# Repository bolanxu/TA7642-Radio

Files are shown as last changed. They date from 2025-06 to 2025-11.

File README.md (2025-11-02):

# TA7642 Radio

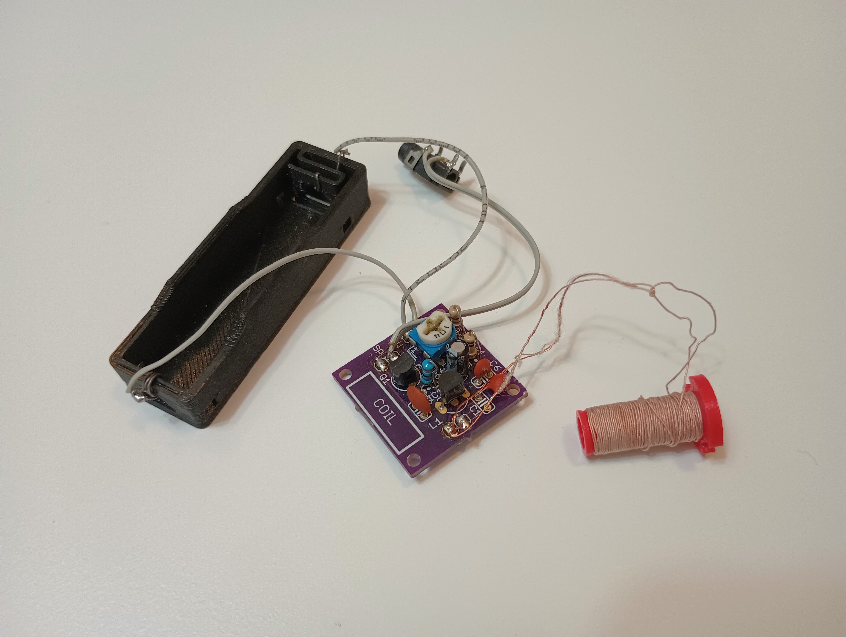
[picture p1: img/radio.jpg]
  
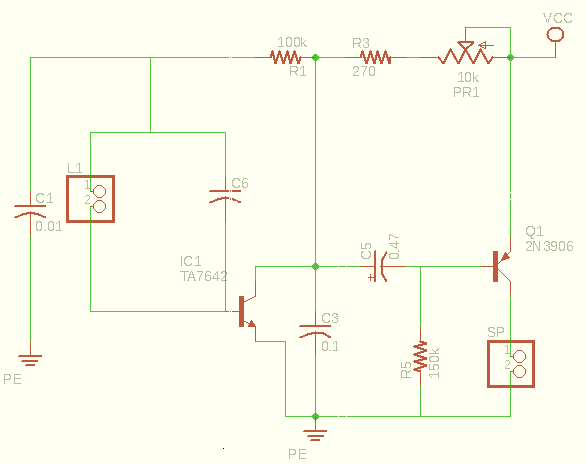
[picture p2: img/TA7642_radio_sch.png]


A very tiny pocket AM radio that runs from a single 1.5 V battery. It's a simple, low‑power receiver built around the TA7642 AM demodulator/amplifier IC with a small tuning coil and a coupling transistor to drive headphones. I designed this as a kit and created the PCB in 2021 (a 5th grade project) to learn about radios, basic electronics, and PCB design. More information in the `/docs` folder (The docs were written by me as a 5th grader, don't expect the best english 😅).

## Features
- Pocket‑sized AM radio
- Powered by a single 1.5 V cell (AA/AAA) or possibly a small 1.5V button battery
- TA7642 AM demodulator and amplifier IC
- Tuning via LC tank (coil + variable capacitor)
- Simple output amplifier transistor (Q1) for headphones/earbuds
- Designed as a kit with a compact PCB

## Circuit (overview)
- The LC tank (coil + capacitor) selects the desired AM frequency.  
- The TA7642 performs RF detection (demodulation) and provides a small amount of audio amplification.  
- A single transistor (Q1) follows the TA7642 to raise the audio level enough for headphones or small earbuds.  
- The schematic is shown above (`img/TA7642_radio_sch.png`)..

## Usage
1. Connect a fresh 1.5 V battery (observe polarity).
2. Plug headphones or earbuds into the audio jack or connect to the audio pads.
3. Slowly adjust the ferrite rod in the coil until you hear a station.
4. Fine‑tune the coil/trimmer for best reception and volume.

Note: This radio is optimized for strong local AM stations and will have limited sensitivity compared with larger receivers.

## Tuning and performance tips
- Use low‑impedance earbuds for better volume from the simple output stage.
- If reception is weak, try repositioning the coil or extending an earbud wire as an antenna.
- Small changes in the tuning capacitor or coil turns produce noticeable frequency shifts—tweak gently.
- The TA7642 and a single‑transistor buffer are designed for simplicity and low voltage operation; don't expect the same performance as higher‑powered receivers.

Enjoy building and listening, tiny radios are a great way to learn the fundamentals of RF and analog electronics!

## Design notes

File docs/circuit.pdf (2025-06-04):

### TA7642 Radio Project

This project, features the basics of a AM Radio. In this project, you will build an AM Radio from 4 capacitors, 4 resistors, a coil, a transistor, and an IC. Below explains the main parts of the radio:

Transistor:
The transistor, Q1, it has to be P-N-P and a small signal amplifier. If you do use a N-P-N type transistor you would need to change the
circuit.

Power source:
Since the operating voltage of the TA7642 IC is no more than 1.5 V, the power in this circuit should also be no more than 1.5 V. If you do use a voltage larger than 1.5 V than your circuit may have a risk of IC and some other components will burn out.

Pot. :
The pot in this circuit is needed for good sensitivity. This pot serves as a adjuster for gain on the TA7642. When the radio signal you are receiving is very strong, you need to adjust the pot to make the gain lower. This way, you can hear the strong station clearly. The same happens when there is a weak station.

TA7642 IC:
This IC (Integrated Circuit) is a IC for amplifying and demodulation purposes. This IC can only receive AM broadcast signals because of its way of demodulation.

C6 capacitor and L1:
This is a LC circuit, you use this to tune in to radio signals. This part of the circuit chooses out one signal from all the others. When you adjust the capacitor or the coil, you are tuning the oscillation frequency between the to components to match the frequency of the radio station.

Q1:
This transistor is used to amplify the audio output signal of the TA7642. Since the audio output signal of the TA7642 is too small to be heard by normal headphones, the transistor can amplify it and gain the volume of the output signal so that it can be heard.

Page 1 out of 3

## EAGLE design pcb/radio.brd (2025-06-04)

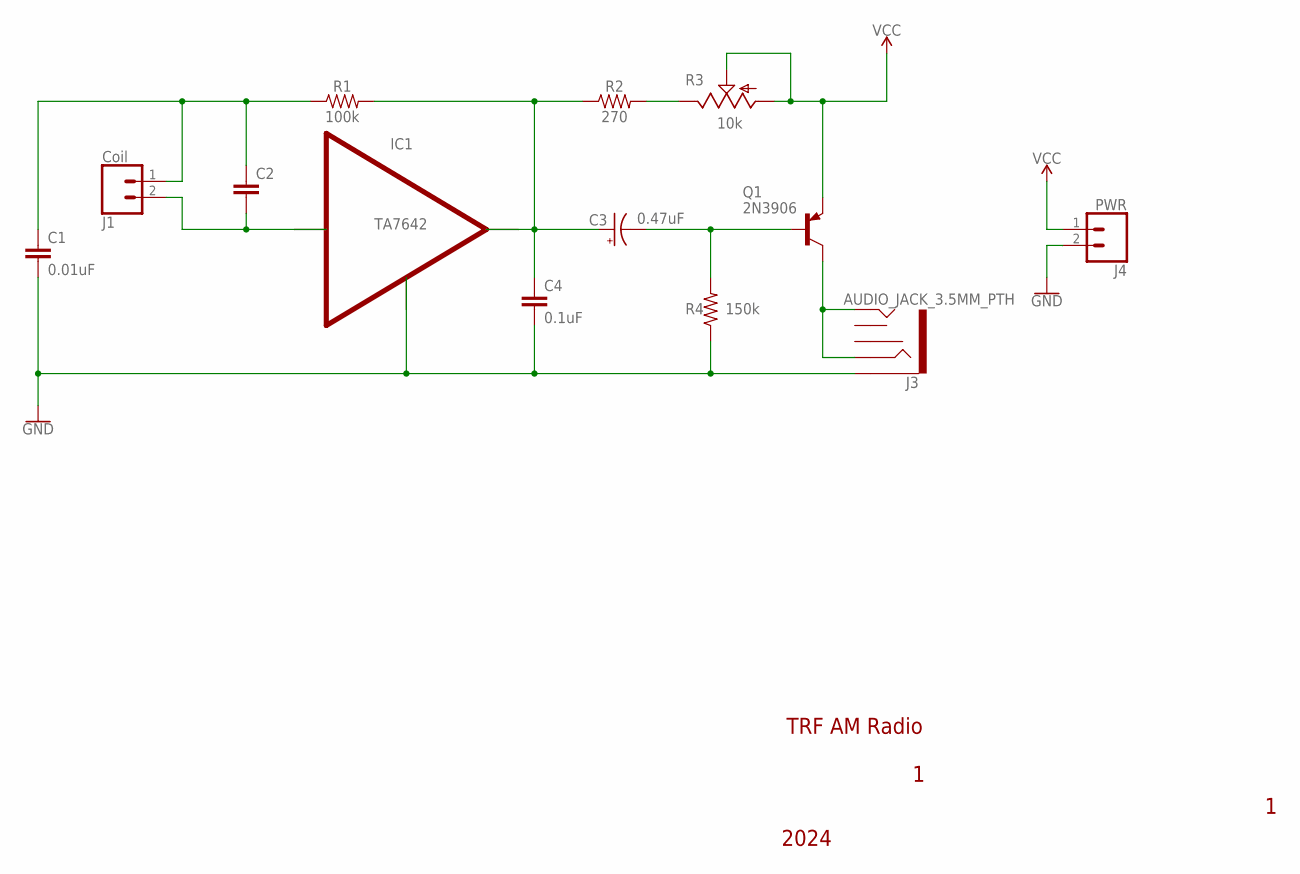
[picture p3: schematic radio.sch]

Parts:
C1: 0.01uF; CAP-PTH-2.54
C2: 22PF-PTH-2.54MM-200V-5%; CAP-PTH-2.54
C3: 0.47uF; CPOL-RADIAL-2.5MM-5MM
C4: 0.1uF; CAP-PTH-2.54
IC1: TA7642; TO92
J1: Coil; 1X02
J3: AUDIO_JACK_3.5MM_PTH; AUDIO-JACK
J4: PWR; 1X02
Q1: 2N3906; TO92
R1: 100k; AXIAL-0.3
R2: 270; AXIAL-0.3
R3: 10k; B25P
R4: 150k; AXIAL-0.3

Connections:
GND: C1.2, C4.2, IC1.2 (GND), J3.SLEEVE, J4.2, R4.P$1 (1)
unnamed: J3.RING, J3.TIP, Q1.1 (C)
unnamed: C3.1 (+), C4.1, IC1.1 (OUT), R1.P$2 (2), R2.P$1 (1)
unnamed: C1.1, C2.1, J1.1, R1.P$1 (1)
unnamed: R2.P$2 (2), R3.E
unnamed: C3.2 (-), Q1.2 (B), R4.P$2 (2)
unnamed: C2.2, IC1.3 (INPUT), J1.2
VCC: J4.1, Q1.3 (E), R3.A, R3.S

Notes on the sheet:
TRF AM Radio
2024

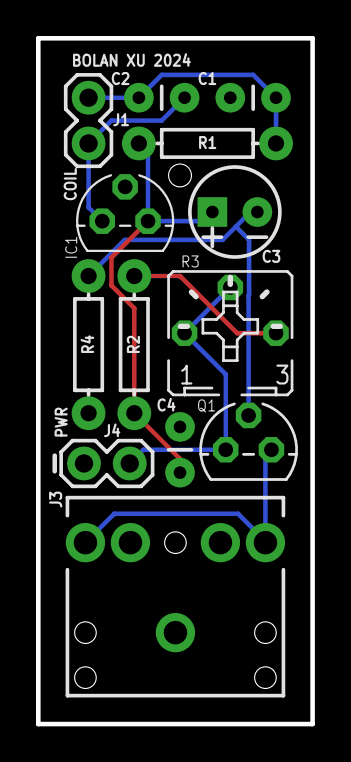
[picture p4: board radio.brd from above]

Board: 2 copper layers, 15.2 x 38.1 mm, 13 parts (0 on the bottom side), 8 nets.

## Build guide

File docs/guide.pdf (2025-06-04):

### TA7642 Radio Project Guide

In this project, we will create a simple AM radio. But first, we have to understand what an AM radio is, and how it works.
An AM radio is a receiver that can receive electromagnetic waves. AM stands for amplitude modulation, and it is a way of transmitting radio signals. There are other types of modulations such as FM, but AM is the simplest. AM radio has many usages, such broadcasting news, music, or entertainment.
In 1901, Guglielmo Marconi did an experiment. He used a primitive spark gap to create oscillations, this was then transmitted through the air. Although his receiver only could receive a very short distance, he still showed that signals can be transmitted without a wired connection. Later, people added new parts to the transmitter so that it could broadcast radio signals that carry sound.
You can also make your own transmitters to broadcast your own radio signals. But, that will be in other projects. You might be wondering if we don’t have a transmitter, then what do we receive? Thankfully, there are many radio stations that are around the country that we can receive.
In this project you learn how an AM radio works, the basics of soldering, and how to check and test the radio circuit.

The theory of the AM radio

There are three main stages of this simple AM radio, tuning, demodulation, preamplifier, and amplification.

Tuning
The tuning stage consists of the inductor L1 and the capacitor C6. This circuit selects one out of all the radio stations, so that you properly hear one radio station instead of hearing all the stations at once. To wind the inductor take the wires and wind the coil with each winding touching the previous winding but not overlapping the it. After you are done, wind on a second layer the same way except this time you wind in the opposite direction.
Pre-Amplification
This stage is all embedded inside the TA7642. This stage first amplifies the signal before demodulating it so that the signal can be stronger.
Demodulation
The demodulator circuit is after the pre-amplification and is also embedded inside the TA7642 IC. What a demodulator does is it separates the audio signal from the carrier wave. The carrier wave is the wave that is transmitted with the audio signal so that it can be transmitted for long distances. But this signal cannot be heard because its frequency is too high for our ears to hear. So we have separate it from the audio wave, so we can hear the audio signal clearly. Along with the TA7642, there are other components that are needed outside of the IC; R3, PR1, and C3. PR1 is a potentiometer, or a variable resistor. It is used to adjust the gain of the amplifier inside the IC. R3 is used to keep the resistance of PR1 and R3 greater than 270 so that the supply voltage isn’t directly feed into the TA7642. Amplification

Page 1 out of 4

Tuning | Pre-Amplification | Demodulation | Amplification

Even though the pre-amplifier and demodulator inside the TA7642 can demodulate the signal, it is still not enough to be heard by normal headphones. So that is why we need an audio amplification stage. The audio amplification stage amplifies the output audio signal of the TA7642 IC so that it can be heard by headphones. The component of the amplification stage include C5, R5, and Q1. Q1 amplifies the signal, while R5 gives the base of the transistor a bias voltage to make the transistor work properly. Soldering Tips
- Use around 25 watt soldering iron
- Solder in this sequence: resistors, capacitors, transistor, TA7642, inductor.
- If you are soldering the TA7642 or the transistor put a alligator clip on the legs of the component. This way the alligator clip can act as an heat sink so that the semiconductor wouldn’t get excessive heat.
Adjustment:
If you find

What’s next for Kids Kits?
- case for the radio
- kits for other AM radio types
- FM radios kits
- transmitter kits

Page 2 out of 4

Component list

Resistors
R1 | 100k
R3 | 270 ohms
R5 | 150k
PR1 10k variable resistor
Capacitors
C1 | 0.01uF
C3 | 0.1uF
C5 | 0.47uF
C6 | can be changed
IC:
IC1 TA7642
Transistors
Q1 S8550
I know it says on the schematic 2n3906, that is a mistake. Coil
L1 variable
Pin Headers
PW | 2x1 female or male header
SP | 2x1 female or male header

Some component names aren’t in order, because of my lack of experience. Even though they aren’t correct they still will work.

Page 3 out of 4

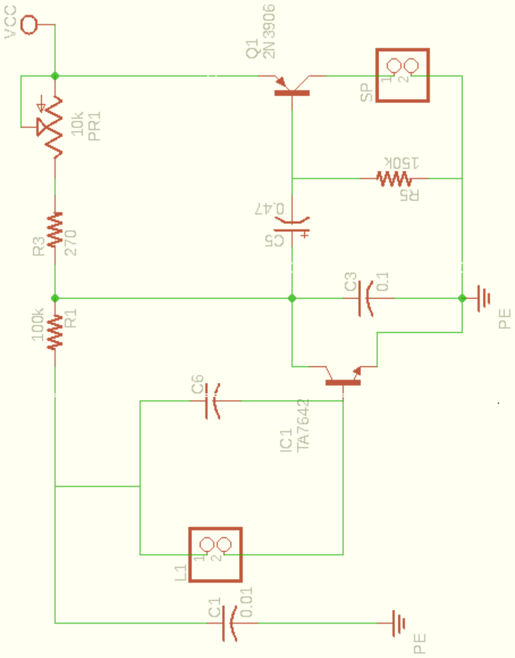
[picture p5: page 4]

Page 4 out of 4

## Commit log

2025-11-02 Add circuit image to README
    Added an image of the radio circuit to the README.
2025-11-02 Enhance README with project details and instructions
    Expanded the description of the AM radio project and added features, circuit overview, usage instructions, and tuning tips.

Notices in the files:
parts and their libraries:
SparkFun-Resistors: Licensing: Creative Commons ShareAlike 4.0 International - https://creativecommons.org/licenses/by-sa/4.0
